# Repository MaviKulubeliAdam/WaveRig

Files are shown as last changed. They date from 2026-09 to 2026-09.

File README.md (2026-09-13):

# WaveRig

An open-hardware ESP32-S3 BLE bridge between amateur radio transceivers and [Wavelog Mobile](https://github.com/MaviKulubeliAdam/Wavelog-Mobile) / [Wavelog](https://github.com/wavelog/wavelog).

WaveRig connects to your radio's CI-V (ICOM) or CAT (Yaesu/Kenwood) interface, reads live frequency, mode and power, and streams it over Bluetooth Low Energy straight into your QSO log — no more typing frequency and mode by hand for every contact.

---

## Status: Early hardware development

- 🔧 Schematic in progress
- ⬜ PCB layout not started yet (65×45 mm, 2-layer target)
- ⬜ Firmware not started yet
- ⬜ No boards fabricated/tested yet

This repository will track schematic/PCB sources, the bill of materials, and firmware once development begins. Contributions, feedback and testing help are welcome even at this stage.

---

## Planned Features

- **CI-V support** — ICOM radios (IC-7300, IC-705, IC-9700, IC-7610, and others) via a 3.5mm jack
- **CAT support** — Yaesu / Kenwood radios (FT-891, FT-991A, FT-DX10, TS-590, TS-890, and others) via RS-232 (DB9) through a MAX202 level shifter
- **BLE GATT service** — frequency, mode, submode, TX power and rig model pushed live to any connected app
- **Rechargeable** — LiPo battery with USB-C charging (TC4056A) and protection (DW01A + FS8205A)
- **USB-C native flashing** — no external USB-serial adapter needed; flash directly over the same USB-C port
- **OLED status display** — shows frequency, mode and connection status at a glance
- **BLE OTA firmware updates** — update via the companion phone app, no cable required (planned)

## Hardware Overview

| | |
|---|---|
| MCU | ESP32-S3-WROOM-1 (N16R8, 16MB flash) |
| Power | LiPo 3.7V, USB-C charging, boost to 3.3V (MT3608) |
| CI-V | 3.5mm jack, open-drain driver (2N7000) |
| CAT / RS-232 | DB9, MAX202EESE+T level shifter |
| Display | I2C OLED (SSD1306, 4-pin connector) |
| PCB | 65×45mm, 2-layer |

Schematic and PCB design are being developed by **Süalp, TA4HCK**. Full BOM, pin assignments and net-by-net connection notes will be published in this repo as the hardware design is finalized.

## Firmware Roadmap

1. BLE GATT service (frequency / mode / submode / power / rig model, notify-based)
2. CI-V protocol parsing (ICOM)
3. CAT protocol parsing (Yaesu / Kenwood)
4. OLED UI
5. BLE OTA updates (phone acts as the bridge to the internet — no Wi-Fi needed on-device)

## Related Projects

- [Wavelog Mobile](https://github.com/MaviKulubeliAdam/Wavelog-Mobile) — the Android companion app WaveRig connects to
- [Wavelog](https://github.com/wavelog/wavelog) — the self-hosted amateur radio logging server

## Contributing

This project is in early hardware development — schematic and PCB files, along with contribution guidelines, will be added as the design stabilizes. Issues and discussion are welcome in the meantime.

## License

Licensed under the [Apache License 2.0](LICENSE).

---

By Erkin, TA4RX / SP9AQG (firmware / software) and Süalp, TA4HCK (schematic / PCB)

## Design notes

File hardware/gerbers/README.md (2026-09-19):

# Gerbers — not yet generated

This folder is a placeholder. Gerber files require a routed PCB (copper
layout), which does not exist yet — only the schematic (`hardware/kicad/`)
has been completed so far.

Once PCB layout/routing is done (by Süalp, TA4HCK), gerbers can be exported
from KiCad (`File → Fabrication Outputs → Gerbers`, or `kicad-cli pcb
export gerbers`) and placed in this folder.

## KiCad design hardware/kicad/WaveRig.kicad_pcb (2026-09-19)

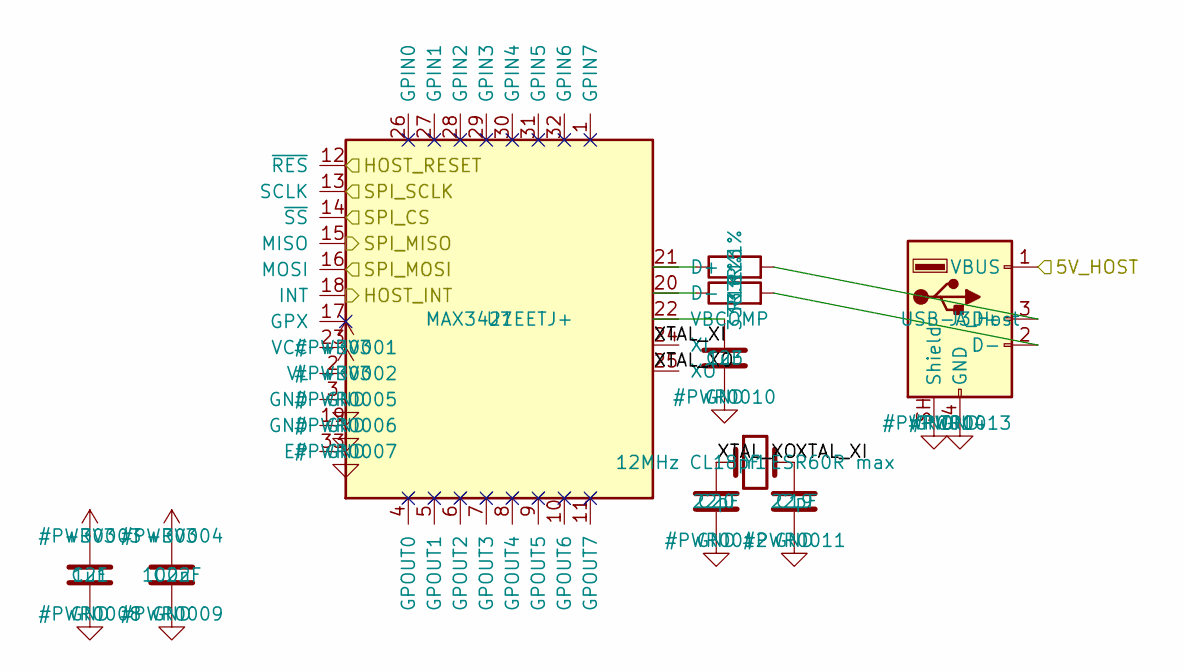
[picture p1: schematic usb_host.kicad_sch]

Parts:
C19, C20: 22pF; C_0603_1608Metric
C21, C23: 1uF; C_0603_1608Metric
C22: 100nF; C_0603_1608Metric
J3: USB-A_Host; USB_A_Receptacle_GCT_USB1046
R15, R16: 33R 1%; R_0603_1608Metric
U7: MAX3421EETJ+; QFN-32-1EP_5x5mm_P0.5mm_EP3.7x3.7mm
Y1: 12MHz CL18pF ESR60R max; Crystal_SMD_HC49-SD

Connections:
+3V3: C21.1, C22.1, U7.2 (VL), U7.23 (VCC); also elsewhere on the board
/HOST_INT: U7.18 (INT); also elsewhere on the board
/HOST_RESET: U7.12 (~RES); also elsewhere on the board
/SPI_CS: U7.14 (~SS); also elsewhere on the board
/SPI_MISO: U7.15 (MISO); also elsewhere on the board
/SPI_MOSI: U7.16 (MOSI); also elsewhere on the board
/SPI_SCLK: U7.13 (SCLK); also elsewhere on the board
/USB_Host/XTAL_XI: C19.1, U7.24 (XI), Y1.2
/USB_Host/XTAL_XO: C20.1, U7.25 (XO), Y1.1
unnamed: J3.3 (D+), R15.2
unnamed: J3.2 (D-), R16.2
unnamed: R15.1, U7.21 (D+)
unnamed: R16.1, U7.20 (D-)
unnamed: C23.1, U7.22 (VBCOMP)

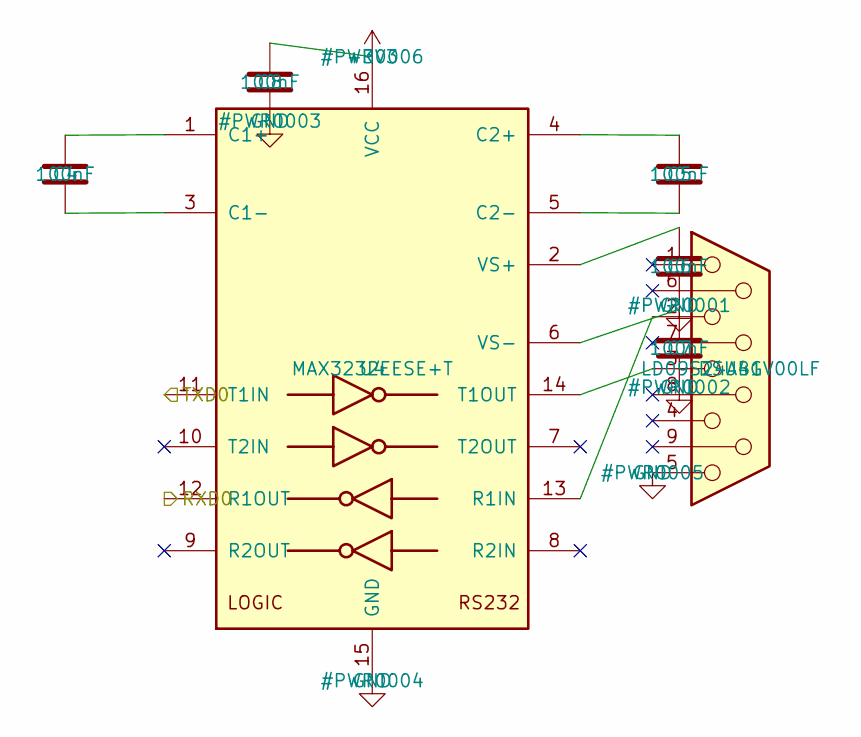
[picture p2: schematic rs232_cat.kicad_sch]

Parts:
C4, C5, C6, C7, C8: 100nF; C_0603_1608Metric
DSUB1: LD09S24A4GV00LF; DSUB-9_Socket_Horizontal_P2.77x2.54mm_EdgePinOffset9.40mm
U4: MAX3232EESE+T; SOIC-16_3.9x9.9mm_P1.27mm

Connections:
+3V3: C8.1, U4.16 (VCC); also elsewhere on the board
/RXD0: U4.12 (R1OUT); also elsewhere on the board
/TXD0: U4.11 (T1IN); also elsewhere on the board
unnamed: C4.1, U4.1 (C1+)
unnamed: C4.2, U4.3 (C1-)
unnamed: C5.1, U4.4 (C2+)
unnamed: C5.2, U4.5 (C2-)
unnamed: DSUB1.2, U4.13 (R1IN)
unnamed: DSUB1.3, U4.14 (T1OUT)
unnamed: C6.1, U4.2 (VS+)
unnamed: C7.1, U4.6 (VS-)

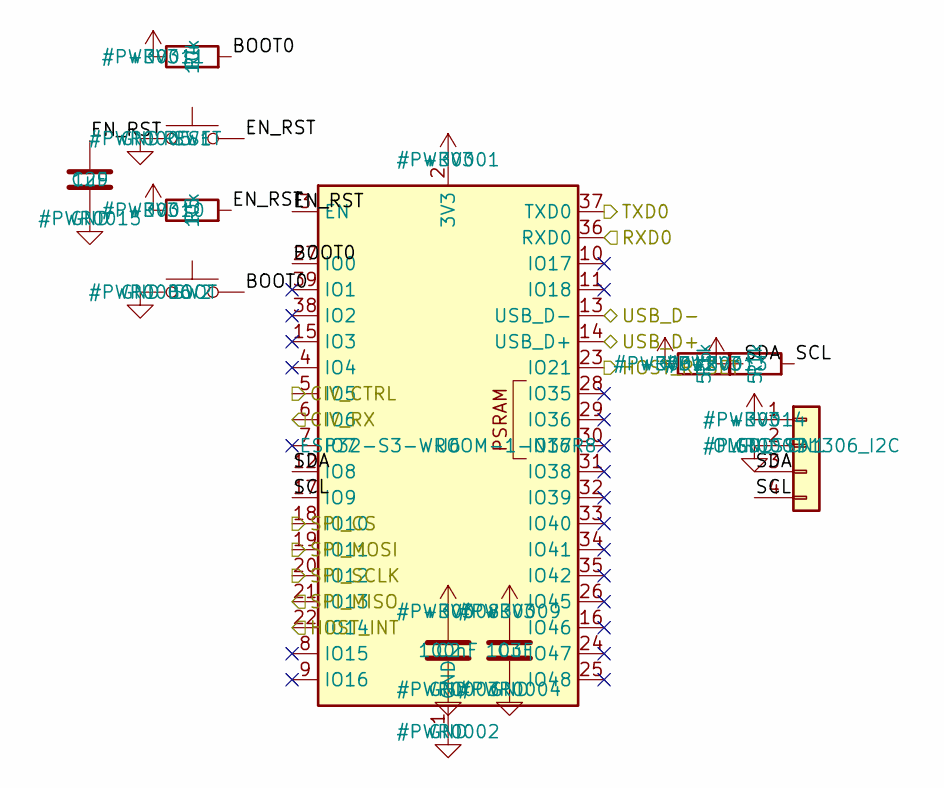
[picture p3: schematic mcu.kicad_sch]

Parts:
C2: 100nF; C_0603_1608Metric
C3: 10uF; C_0603_1608Metric
C29: 1uF; C_0603_1608Metric
CN1: OLED_SSD1306_I2C; JST_PH_B4B-PH-K_1x04_P2.00mm_Vertical
R4, R5: 10k; R_0603_1608Metric
R6, R7: 5.1k; R_0603_1608Metric
SW1: RESET; SW_SPST_B3S-1000
SW2: BOOT; SW_SPST_B3S-1000
U6: ESP32-S3-WROOM-1-N16R8; ESP32-S3-WROOM-1

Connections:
+3V3: C2.1, C3.1, CN1.1, R4.1, R5.1, R6.1, R7.1, U6.2 (3V3); also elsewhere on the board
/CIV_CTRL: U6.5 (IO5); also elsewhere on the board
/CIV_RX: U6.6 (IO6); also elsewhere on the board
/HOST_INT: U6.22 (IO14); also elsewhere on the board
/HOST_RESET: U6.23 (IO21); also elsewhere on the board
/MCU/BOOT0: R4.2, SW2.2, U6.27 (IO0)
/MCU/EN_RST: C29.1, R5.2, SW1.2, U6.3 (EN)
/MCU/SCL: CN1.4, R7.2, U6.17 (IO9)
/MCU/SDA: CN1.3, R6.2, U6.12 (IO8)
/RXD0: U6.36 (RXD0); also elsewhere on the board
/SPI_CS: U6.18 (IO10); also elsewhere on the board
/SPI_MISO: U6.21 (IO13); also elsewhere on the board
/SPI_MOSI: U6.19 (IO11); also elsewhere on the board
/SPI_SCLK: U6.20 (IO12); also elsewhere on the board
/TXD0: U6.37 (TXD0); also elsewhere on the board
/USB_D+: U6.14 (USB_D+); also elsewhere on the board
/USB_D-: U6.13 (USB_D-); also elsewhere on the board

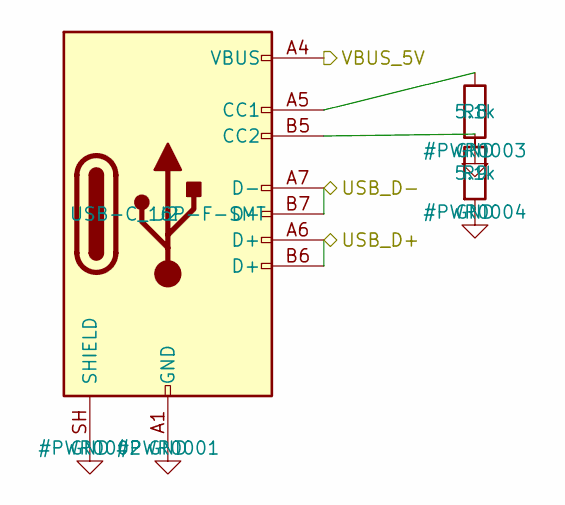
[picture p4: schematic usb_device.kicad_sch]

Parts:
J2: USB-C_16P-F-SMT; USB_C_Receptacle_GCT_USB4115-03-C
R8, R9: 5.1k; R_0603_1608Metric

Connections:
/USB_D+: J2.A6 (D+), J2.B6 (D+); also elsewhere on the board
/USB_D-: J2.A7 (D-), J2.B7 (D-); also elsewhere on the board
unnamed: J2.A5 (CC1), R8.1
unnamed: J2.B5 (CC2), R9.1

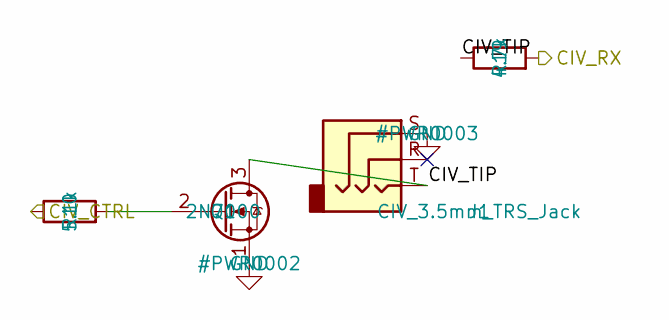
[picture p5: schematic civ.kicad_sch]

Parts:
J1: CIV_3.5mm_TRS_Jack; Jack_3.5mm_CUI_SJ1-3523N_Horizontal
Q1: 2N7000; TO-92_Inline
R10: 5.1k; R_0603_1608Metric
R19: 4.7k; R_0603_1608Metric

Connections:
/CIV/CIV_TIP: J1.T, Q1.3 (D), R19.1
/CIV_CTRL: R10.1; also elsewhere on the board
/CIV_RX: R19.2; also elsewhere on the board
unnamed: Q1.2 (G), R10.2

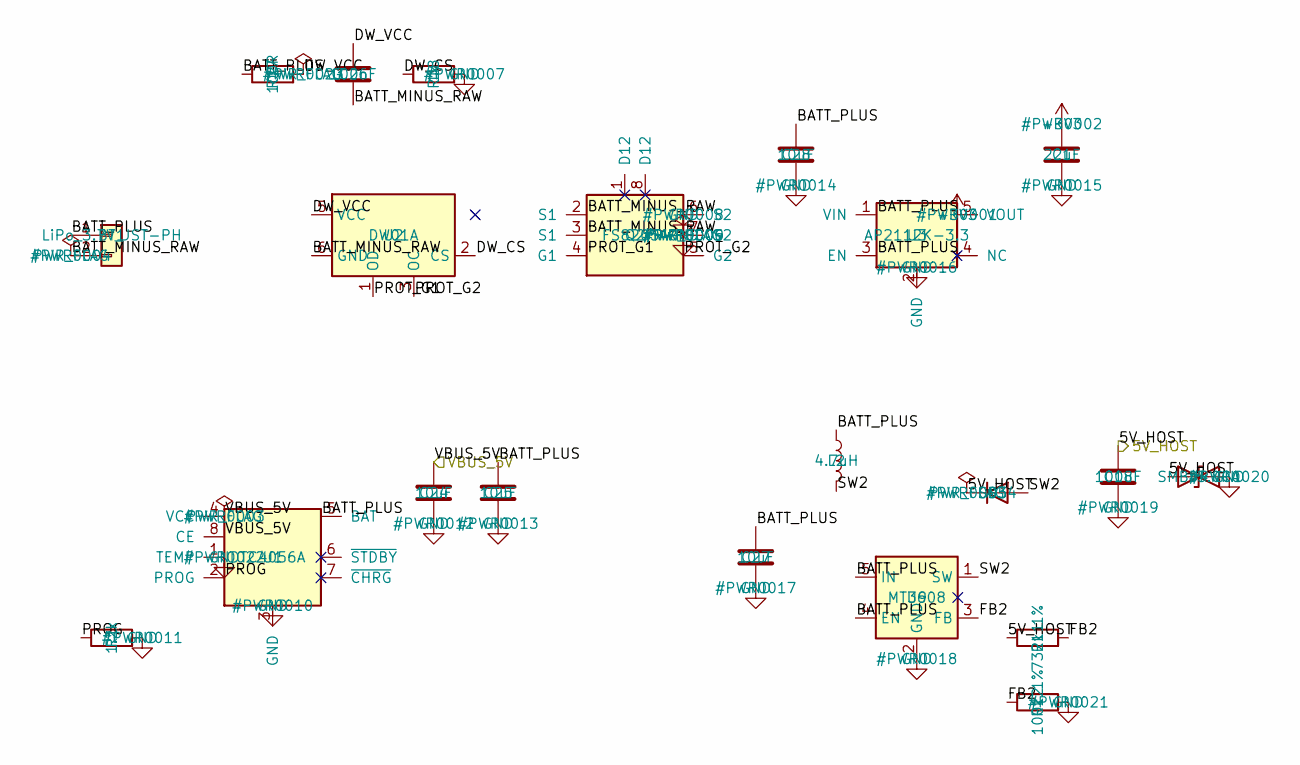
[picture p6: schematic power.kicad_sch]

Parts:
BT1: LiPo_3.7V_JST-PH; JST_PH_B2B-PH-K_1x02_P2.00mm_Vertical
C1: 22uF; C_0805_2012Metric
C18: 100uF; C_1206_3216Metric
C24, C25, C27, C28: 10uF; C_0805_2012Metric
C26: 100nF; C_0603_1608Metric
D3: SS34; D_SMA
D4: SMBJ5.0CA; D_SMB
L2: 4.7uH; L_6.3x6.3_H3
Q2: FS8205A; TSSOP-8_4.4x3mm_P0.65mm
R1: 1.2k; R_0603_1608Metric
R11: 732k 1%; R_0603_1608Metric
R12: 100k 1%; R_0603_1608Metric
R17: 100R; R_0603_1608Metric
R18: 1k; R_0603_1608Metric
U1: TC4056A; SOIC-8_3.9x4.9mm_P1.27mm
U2: DW01A; SOT-23-6
U3: AP2112K-3.3; SOT-23-5
U9: MT3608; SOT-23-6

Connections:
+3V3: C1.1, U3.5 (VOUT); also elsewhere on the board
/Power/BATT_PLUS: BT1.1, C25.1, C27.1, C28.1, L2.1, R17.1, U1.5 (BAT), U3.1 (VIN), U3.3 (EN), U9.4 (EN), U9.5 (IN)
/Power/DW_CS: R18.1, U2.2 (CS)
/Power/FB2: R11.2, R12.1, U9.3 (FB)
/Power/PROG: R1.1, U1.2 (PROG)
/Power/PROT_G1: Q2.4 (G1), U2.1 (OD)
/Power/PROT_G2: Q2.5 (G2), U2.3 (OC)
/Power/SW2: D3.2 (A), L2.2, U9.1 (SW)

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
Board: 2 copper layers, 56 parts (0 on the bottom side), 48 nets, no tracks yet.

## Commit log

2026-09-13 docs: correct schematic status, credit Süalp TA4HCK for hardware design
2026-09-13 Update schematic status in README
2026-09-19 feat: add WaveRig v1 schematic (KiCad)
    Six hierarchical sheets: Power (LiPo charge/protection + dual boost for
    3.3V system rail and 5V USB-host rail), MCU (ESP32-S3-WROOM-1 + OLED +
    reset/boot), USB_Device (native USB-C, charge/flash), CIV (ICOM 3.5mm
    jack), RS232_CAT (MAX232/202 + DB9 for older Kenwood/Yaesu), and a new
    USB_Host block (MAX3421E + USB-A) added to support radios like the
    FT-891 whose CAT is USB-only.
    Draft status: TC4056A/FS8205A/MAX3421E use custom symbols (no exact
    library part existed) with pin numbers that need datasheet verification.
    5V_HOST feedback-divider values are placeholders. ERC is clean (0
    errors/warnings) but this is a starting point for Süalp (TA4HCK) to
    rev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
    [WaveRig.kicad_pcb, WaveRig.kicad_sch, civ.kicad_sch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]
2026-09-19 fix: repair schematic connectivity, real MAX3421E pinout, footprint assignment
    - Root sheet pins were placed outside the sheet boxes, so no cross-sheet
    net (IO5->CI-V, USB D+/D-, SPI, VBUS_5V, 5V_HOST) was actually connected.
    Rebuilt pins on the sheet borders with wire stubs + labels.
    - MCU: SW1/SW2 pin 2 carried both GND and EN/BOOT0 (short to ground);
    GND moved to pin 1. Unused ESP32 GPIOs marked no-connect.
    - USB_Host rebuilt around the real MAX3421E TQFN-32 pinout (datasheet
    19-3953): 33 ohm D+/D- series resistors, 1uF VCC/VBCOMP, 0.1uF VL.
    - J1 now AudioJack3 (T/R/S) with CUI SJ1-3523N footprint; Q1 is a real
    2N7000 (TO-92).
    - PWR_FLAGs added; ERC (raw kicad-cli) has 0 errors.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
    [WaveRig.kicad_pcb, WaveRig.kicad_sch, civ.kicad_sch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]
2026-09-19 fix: datasheet audit - correct charger pinout, LDO for 3V3, DW01A/FS8205A, MAX3232, CI-V RX
    [WaveRig.kicad_pcb, WaveRig.kicad_sch, civ.kicad_sch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]
2026-09-19 docs: specify Y1 crystal parameters (CL18pF, ESR 60R max) per MAX3421E datasheet
    [WaveRig.kicad_pcb, usb_host.kicad_sch]
2026-09-19 fix: unique sheet page numbers, upgrade schematics to KiCad 10 format
    [WaveRig.kicad_sch, civ.kicad_sch, mcu.kicad_sch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]
2026-09-23 Refactored the power schematic.
    [WaveRig.kicad_sch, power.kicad_sch]
